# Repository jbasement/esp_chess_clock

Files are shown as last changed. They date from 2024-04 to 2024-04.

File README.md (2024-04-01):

# Selfmade Chess Clock with 3D printed case based on ESP32
Chess clock built with esp32 d1 mini

This repo contains the wiring diagram, CAD file for the 3D printed case and the code to run on the esp32.

## Components

### Electrical

1. [ESP32 D1 Mini](https://www.az-delivery.de/en/products/esp32-d1-mini)
2. [TM1637 7-Bit display](https://www.az-delivery.de/en/products/4-digit-display)
3. [0.96 OLED display](https://www.az-delivery.de/en/products/0-96zolldisplay)
4. [KY-021 reed sensor](https://www.az-delivery.de/en/products/reed-sensor-modul)
5. [18650 battery shield](https://www.amazon.de/diymore-Battery-Micro-USB-Anschluss-Raspberry-Arduino/dp/B0822Q4VS4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)
6. [Tactile push button](https://www.amazon.de/RUNCCI-YUN-Drucktastenschalter-Mikroschalter-oberfl%C3%A4chenmontierte-Schaltplatte%EF%BC%8C/dp/B07WPBQXJ9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)

### Misc

1. [Tiny magnets](https://www.amazon.de/Magnetpro-Selbstklebende-Klebemagnete-Magnetisiert-Pr%C3%A4sentation/dp/B0BJQ918KX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)
2. [Threaded inserts M2](https://www.amazon.de/qxayxa-Gewindeeinsatz-Einpressmutter-Gewindebuchsen-Kunststoffteile/dp/B0CJM2Z7YJ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)
3. [M2 screws](https://www.amazon.de/FandWay-Linsenkopfschrauben-Schrauben-Unterlegscheiben-Sortiment/dp/B09SH5N5T4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)

## Assembly

Of course this is up to personal preference but this is how I assembled everything.

### Soldering

1. Parallel chain all peripheral components (Ground + VCC)
    1. Already add data to components when soldering the power lines
2. Superglue buttons to the case
3. Solder ground and data line to buttons
4. Solder every data line to the ESP32
5. Solder the power lines (ESP32, peripherals and ground for buttons) to the battery shield

### Case 

1. Superglue magnets into magnet holder
2. Add threaded inserts into holes
3. Screw in every component in place
    1. OLED display has to be superglued as case was to thin to add screws

## Known issues

1. OLED display has to be superglued into place
2. Between 5-8min fixed time the first move subtracts 2 seconds on start and not 1 as it should

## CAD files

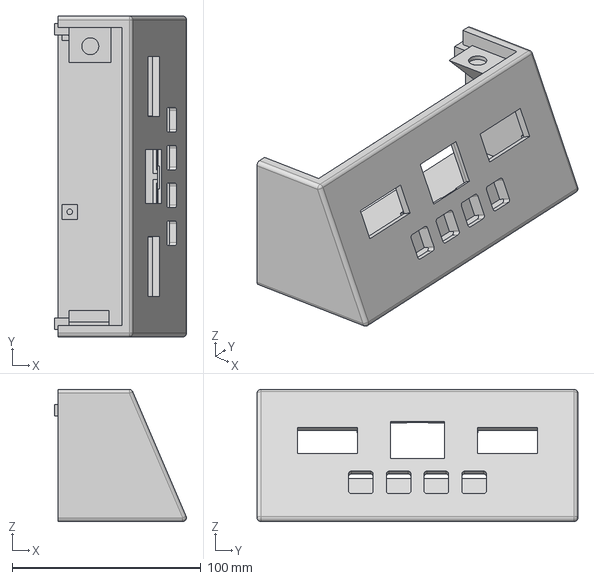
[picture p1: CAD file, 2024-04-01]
ChessClockCAD.step
69.9 x 170.0 x 70.0 mm

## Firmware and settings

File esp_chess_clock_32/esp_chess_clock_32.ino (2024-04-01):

#include <Wire.h>
#include <Adafruit_GFX.h>
#include <Adafruit_SSD1306.h>
#include <Fonts/FreeMono9pt7b.h>
#include <TM1637TinyDisplay.h>

#define SCREEN_WIDTH 128
#define SCREEN_HEIGHT 64

// 7bit display
#define CLK_PIN 19
#define DIO_PIN 23
#define CLK_PIN2 26
#define DIO_PIN2 18

Adafruit_SSD1306 display(SCREEN_WIDTH, SCREEN_HEIGHT, &Wire, -1);
TM1637TinyDisplay timer(CLK_PIN, DIO_PIN);
TM1637TinyDisplay timer2(CLK_PIN2, DIO_PIN2);

// Pin setup
uint8_t buttonBackPin = 27;
uint8_t buttonDownPin = 25;
uint8_t buttonUpPin = 32;
uint8_t buttonEnterPin = 12;
const int reedSwitchPin = 10;


// game modes
enum GameMode { MODE_5_0,
                MODE_5_3,
                MODE_10_3,
                MODE_15_5,
                MODE_CUSTOM };
GameMode modes[] = { MODE_5_0, MODE_5_3, MODE_10_3, MODE_15_5, MODE_CUSTOM };
const char* modeStrings[] = { "5+0", "5+3", "10+3", "15+5", "Custom" };
const int numModes = sizeof(modes) / sizeof(modes[0]);
const int maxDisplayItems = 3;

// menu vars
int selectedItem = 0;
int startIndex = 0;
void drawMenu();

class ModeHandler {
public:
  void handleMode(GameMode mode) {
    switch (mode) {
      case MODE_CUSTOM:
        customTime();
        break;
      default:
        presetTime(modeStrings[mode]);
    }
    drawMenu();
  }

private:
  int fixedT = 1;
  int variableT = 0;
  const unsigned long secondInMillis = 1000;  // One second in milliseconds

  // set fixedT and variableT based on user input
  void customTime() {
    delay(200);
    // Ask for fixed time (0-99)
    fixed:
    while (true) {
      if (digitalRead(buttonEnterPin) == LOW && fixedT > 0) {
        break;  // Exit loop if 'e' is pressed
      } else if (digitalRead(buttonUpPin) == LOW && fixedT < 99) {
        fixedT++;
      } else if (digitalRead(buttonDownPin) == LOW && fixedT > 1) {
        fixedT--;
      } else if (digitalRead(buttonBackPin) == LOW) {
        return;
      }
      displayfixedT();
      delay(100);
    }

    delay(200);
    // Ask for variable time (0-30)
    while (true) {
      if (digitalRead(buttonEnterPin) == LOW) {
        break;  // Exit loop if 'e' is pressed and variableT is greater than 0
      } else if (digitalRead(buttonUpPin) == LOW && variableT < 30) {
        variableT++;
      } else if (digitalRead(buttonDownPin) == LOW && variableT > 0) {
        variableT--;
      } else if (digitalRead(buttonBackPin) == LOW) {
        goto fixed;
      }
      displayvariableT();
      delay(100);  // Add a small delay
    }

    gameMode(fixedT, variableT);
  }

  // parse presetTime mode string into fixedT and variableT variables
  void presetTime(const String& time) {
    // Find the position of the '+' character in the string
    int plusPos = time.indexOf('+');

    // Extract the fixed time substring from the beginning of the string
    fixedT = time.substring(0, plusPos).toInt();
    // Extract the variable time substring after the '+' character
    variableT = time.substring(plusPos + 1).toInt();

    gameMode(fixedT, variableT);
  }

  // main game function that contains init and game loop
  void gameMode(int fixedT, int variableT) {
    // Init player times
    float p1 = fixedT;
    float p2 = fixedT;

    int moves = 2;                     // Calculate moves and start at 2 so moves can be calculated using (moves/2)
    bool gameActive = false;           // used to check if clock is running
    unsigned long previousMillis = 0;  // Variable to store the last time the value was updated
    bool p1Active;                     // check on which side the chess switch is. Sensor is located on left side. Left side = P1; right side = P2
    int currentSwitchState = digitalRead(reedSwitchPin);
    int previousSwitchState = currentSwitchState;

    // check who has first turn
    if (currentSwitchState == LOW) {
      p1Active = true;
    } else {
      p1Active = false;
    }

    delay(100);  // So game doesnt immediately start because enter is still pressed.

    // main game loop
    while (true) {
      // Display layout init
      showActiveGame(moves);

      // Update player time
      if (gameActive) {
        if (p1Active) {
          updatePlayerTime(p1, gameActive, previousMillis);
        } else {
          updatePlayerTime(p2, gameActive, previousMillis);
        }
      }

      // Show time on 7-bit display
      showGameTime(p1, p2);

      // Check reed sensor state
      currentSwitchState = digitalRead(reedSwitchPin);

      // Controls
      if (digitalRead(buttonBackPin) == LOW) {  // back to menu
        return;
      } else if (digitalRead(buttonEnterPin) == LOW) {  // start & stop game by pressing enter, by flipping gameActive bool
        gameActive = !gameActive;
      } else if (gameActive && currentSwitchState != previousSwitchState) {  // switch active player
        if (p1Active) {
          p1 += static_cast<float>(variableT) / 60.0;
        } else {
          p2 += static_cast<float>(variableT) / 60.0;
        }
        p1Active = !p1Active;
        moves++;
        previousSwitchState = currentSwitchState;
      } else if (!gameActive && currentSwitchState != previousSwitchState) {  // start game when it is stopped and the switch is hit
        gameActive = !gameActive;
        p1Active = !p1Active;
        previousSwitchState = currentSwitchState;        
      }
      delay(50);  // Add a small delay
    }
  }

  void updatePlayerTime(float& playerTime, bool& gameActive, unsigned long& previousMillis) {
    unsigned long currentMillis = millis();  // Get the current time

    // This is the clock for the active player. Check if one second has passed
    if (currentMillis - previousMillis >= secondInMillis) {
      // Update the value every second
      playerTime -= 1.0 / 60.0;                                                          // Decrease by one minute
      int seconds = static_cast<int>((playerTime - static_cast<int>(playerTime)) * 60);  // Extract the seconds

      // Update the last time the value was updated
      previousMillis = currentMillis;

      // Check if the timer has reached 0:00
      if (playerTime <= 0.0 && seconds <= 0) {
        gameActive = false;
      }
    }
  }

  void displayfixedT() {
    // Display the current fixed time value
    display.clearDisplay();
    display.setTextColor(WHITE);
    display.setCursor(0, 10);
    display.setFont(&FreeMono9pt7b);
    display.print("Fixed Time: ");
    display.println(fixedT);
    display.display();
  }

  void displayvariableT() {
    // Display the current variable time value
    display.clearDisplay();
    display.setTextColor(WHITE);
    display.setCursor(0, 10);
    display.setFont(&FreeMono9pt7b);
    display.print("Variable Time: ");
    display.println(variableT);
    display.display();
  }

  void showGameTime(float p1, float p2) {
    int p1Min = static_cast<int>(p1);
    int p1Sec = static_cast<int>((p1 - p1Min) * 60);
    int p2Min = static_cast<int>(p2);
    int p2Sec = static_cast<int>((p2 - p2Min) * 60);
    timer.showNumberDec(p1Min * 100 + p1Sec, 0b01000000, true);
    timer2.showNumberDec(p2Min * 100 + p2Sec, 0b01000000, true);
  }

  void showActiveGame(int moves) {
    display.clearDisplay();
    display.setTextColor(WHITE);
    display.setCursor(0, 10);
    display.setFont(&FreeMono9pt7b);
    display.println("Game mode");
    display.print(fixedT);
    display.print("+");
    display.println(variableT);
    display.print("Moves: ");
    display.print(moves / 2);
    display.display();
  }
};

ModeHandler modeHandler;

void drawMenu() {
  display.clearDisplay();
  display.setTextColor(WHITE);
  display.setCursor(0, 10);
  display.setFont(&FreeMono9pt7b);
  display.println("Select mode:");

  timer.showNumberDec(0 * 100 + 0, 0b01000000, true);
  timer2.showNumberDec(0 * 100 + 0, 0b01000000, true);

  for (int i = 0; i < maxDisplayItems; i++) {
    int index = (startIndex + i) % numModes;
    if (index == selectedItem) {
      display.println("> " + String(modeStrings[index]));  // Display the selected mode with ">"
    } else {
      display.println("  " + String(modeStrings[index]));  // Display other modes without ">"
    }
  }

  display.display();
}

void setup() {
  // !! This delay is very important to avoid a race condition between the esp and the peripherals
  // As both are powered by battery at the same time and we have to make sure to first trying to access the peripherals when they are already powerered
  delay(2000); 
  timer.begin();
  timer2.begin();
  timer.flipDisplay(true);
  display.begin(SSD1306_SWITCHCAPVCC, 0x3C);

  // Init pins
  pinMode(buttonBackPin, INPUT_PULLUP);
  pinMode(buttonUpPin, INPUT_PULLUP);
  pinMode(buttonDownPin, INPUT_PULLUP);
  pinMode(buttonEnterPin, INPUT_PULLUP);
  pinMode(reedSwitchPin, INPUT_PULLUP);

  drawMenu();  // Draw the initial menu
}

// This main loop focuses on the menu navigation. Once an option was selected it will call the modeHandler which has again loops to catch input.
void loop() {
  if (digitalRead(buttonUpPin) == LOW) {
    selectedItem = (selectedItem - 1 + numModes) % numModes;
  } else if (digitalRead(buttonDownPin) == LOW) {
    selectedItem = (selectedItem + 1) % numModes;
  } else if (digitalRead(buttonEnterPin) == LOW) {
    modeHandler.handleMode(modes[selectedItem]);
  }

  // Update startIndex logic moved outside the if statements
  if (selectedItem < startIndex) {
    startIndex = selectedItem;
  } else if (selectedItem >= startIndex + maxDisplayItems) {
    startIndex = selectedItem - maxDisplayItems + 1;
  }

  drawMenu();
  delay(100);
}

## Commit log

2023-12-28 add current state
2023-12-29 timer working with 2 players
2024-01-08 add reed sensor
2024-01-13 Adjust pins for esp32
2024-03-29 Remove serial.println and switch input pins
2024-04-01 fix active time with switch bug
    [esp_chess_clock_32.ino]
2024-04-01 Add readme and more files
    [ChessClockCAD.step]
